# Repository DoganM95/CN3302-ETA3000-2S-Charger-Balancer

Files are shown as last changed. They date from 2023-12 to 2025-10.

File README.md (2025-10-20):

# Intro

A dual cell charger (3-6V 4A in, 8.4V ~3A out) combined with active balancing (1.3A).   
- The charging part makes sure to load the battery pack to 8.4v
- The balancing part makes sure to keep both batteries at the same voltage always, by charging the lower one using the higher one (active balancing)

Having these combined will in theory give the perfect 2S bms, so that batteries won't die, charge fast and don't waste energy.  

Any buyable bms i have tested so far fails to keep both batteries at the same voltage, so that one is e.g. 4.6v and the other 3.8v, resulting in 8.4v total but leading to damage/death of the overcharged cell, hence this proect to solve the issue and have a reliable, hackable solution.  

Still in concept phase, highly experimental and untested. Even the pcb traces are not wide enough to support the supplied current and would probably delaminate or catch fire.  

Releases starting with v1 or higher can be used and are tested.

# PCB

<table>
  <tr>
    <td>
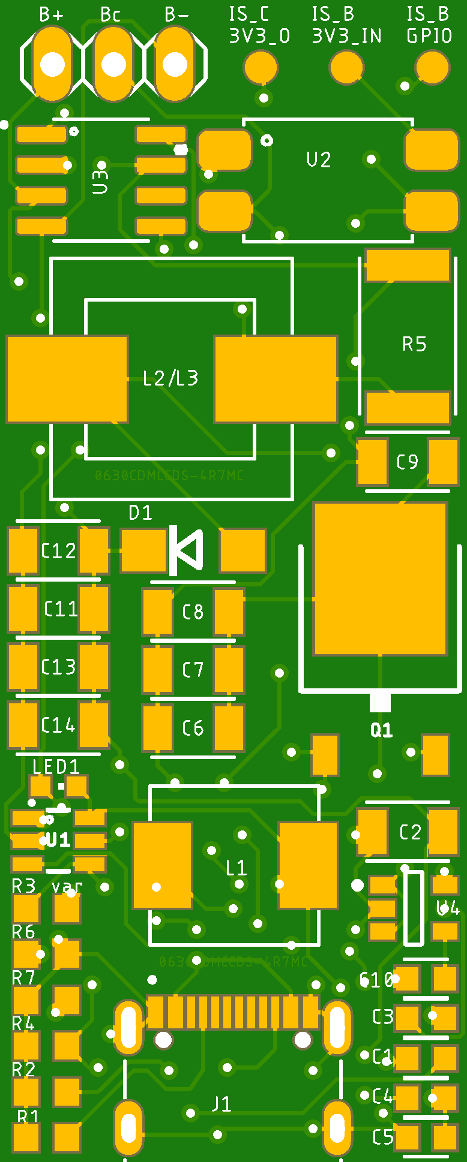
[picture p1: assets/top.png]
PCB Top View
      
    </td>
    <td>
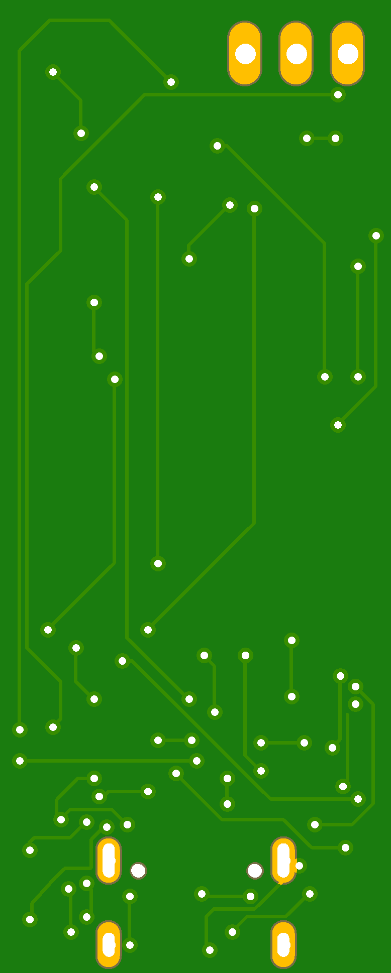
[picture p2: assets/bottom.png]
PCB Bottom View
      
    </td>
  </tr>
</table>

## BOM

Most parts a salvaged from commercially available modules, which are dirt-cheap on aliexpress:
- [Charging module (2S, 4A](https://a.aliexpress.com/_EuYAQFK)
- [Balancing module (2S, 1.3A, active)](https://s.click.aliexpress.com/e/_EuIdQJ6)

So all parts of those modules can be desoldered using a hot-plate and solder3d on this project's pcb.

<table>
  <thead>
    <tr>
      <th>Component Symbol</th>
      <th>Size</th>
      <th>Value</th>
      <th>Side Notes</th>
    </tr>
  </thead>
  <tbody>
    <tr><td>C1</td><td>0603</td><td>10nF</td><td></td></tr>
    <tr><td>C2</td><td>1206</td><td>22uF</td><td></td></tr>
    <tr><td>C3</td><td>0603</td><td>10nF</td><td></td></tr>
    <tr><td>C4</td><td>0603</td><td>10nF</td><td></td></tr>
    <tr><td>C5</td><td>0603</td><td>10nF</td><td></td></tr>
    <tr><td>C6</td><td>1206</td><td>22uF</td><td></td></tr>
    <tr><td>C7</td><td>1206</td><td>22uF</td><td></td></tr>
    <tr><td>C8</td><td>1206</td><td>22uF</td><td></td></tr>
    <tr><td>C9</td><td>1206</td><td>22uF</td><td></td></tr>
    <tr><td>C10</td><td>0603</td><td>10nF</td><td></td></tr>
    <tr><td>C11</td><td>1206</td><td>22uF</td><td></td></tr>
    <tr><td>C12</td><td>1206</td><td>22uF</td><td></td></tr>
    <tr><td>C13</td><td>1206</td><td>22uF</td><td></td></tr>
    <tr><td>C14</td><td>1206</td><td>22uF</td><td></td></tr>
    <tr><td>D1</td><td>sma</td><td>SS54 (Schottky)</td><td></td></tr>
    <tr><td>L1</td><td>0630 (6.6x6.6x3mm)</td><td>2.2 uH</td><td></td></tr>
    <tr><td>L2 / L3</td><td>any</td><td>2.2 uH</td><td>any that fits there by size</td></tr>
    <tr><td>LED1</td><td>0603</td><td>led</td><td>any color, check R3</td></tr>
    <tr><td>Q1</td><td>TO-252-2</td><td>KND3203b</td><td></td></tr>
    <tr><td>R1</td><td>0603</td><td>5.1 kOhm</td><td></td></tr>
    <tr><td>R2</td><td>0603</td><td>5.1 kOhm</td><td></td></tr>
    <tr><td>R3</td><td>0603</td><td>var Ohm</td><td>choose one that fits your LED1</td></tr>
    <tr><td>R4</td><td>0603</td><td>25 kOhm</td><td></td></tr>
    <tr><td>R5</td><td>2512</td><td>0.015 Ohm</td><td></td></tr>
    <tr><td>R6</td><td>0603</td><td>10 kOhm</td><td></td></tr>
    <tr><td>R7</td><td>0603</td><td>10 kOhm</td><td></td></tr>
    <tr><td>U1</td><td>sot23-6</td><td>ETA3000</td><td></td></tr>
    <tr><td>U2</td><td>smt</td><td>PC817X</td><td></td></tr>
    <tr><td>U3</td><td>sop8</td><td>CN3302</td><td></td></tr>
    <tr><td>U4</td><td>sot23-5</td><td>MIC5219 3.3v</td><td></td></tr>
  </tbody>
</table>

## Schematic

### By Datasheets

Follows the recommendations and schematics of the datasheets



### By reverse engineered chinese modules

Follows the reverse engineered chinese pcb modules, so they are merged into this pcb to minimize the need of additional components (just move parts over).

Todo

## Key Takeaways

- The status group of the `ETA3000` consisting of a red led and a 1k resistor use `BatC` as one pole and `SW` as the other. Thus it does not have a real `GND` but current flows with `BatC` acting as Vcc and `SW` acting as `GND` for the led
- The said red status led connections could also be exploited to power an optocoupler, so the `GND` stays independent for this part of the circuit and status becomes measurable using e.g. an arduino
- Connecting `BIAS` or `SW` of the `ETA3000` to the `GND`, which is the negative side of the 2 batteries connected in series, kills the IC and from there it gets very hot while being powered
- None of the 2 ic's (CN3302 && ETA3000) have a symbol in snapeda, so generic packages are used and pins renamed to match this ic

## Resources

### Charger IC: CN3302 (sop-8)

- [Datasheet (EN) of CN3302](https://github.com/DoganM95/2S-Charge-Balance-Pcb/files/13642784/CN3302.zh-CN.en.pdf)
- [Datasheet (CN) of CN3302](https://jlcpcb.com/partdetail/ShangHai_ConsonanceElec-CN3302/C559039)

### Active balancer IC: ETA3000 (sot23-6)
- [Writeup on ETA3000](https://www.beyondlogic.org/review-li-ion-lipo-lifepo4-lithium-battery-active-equalizer-balancer-energy-transfer-board/)
- [Datasheet of ETA3000](https://github.com/DoganM95/2S-Charge-Balance-Pcb/files/13648156/ETA3000-ETA.pdf)

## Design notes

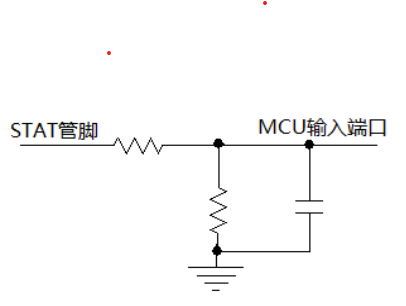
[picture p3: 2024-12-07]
assets/snippet.png

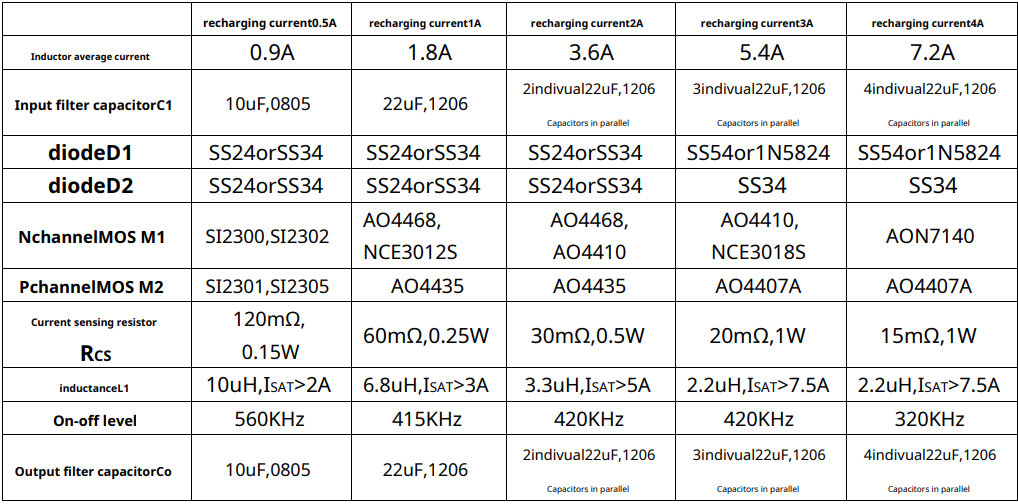
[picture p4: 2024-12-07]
assets/table.png

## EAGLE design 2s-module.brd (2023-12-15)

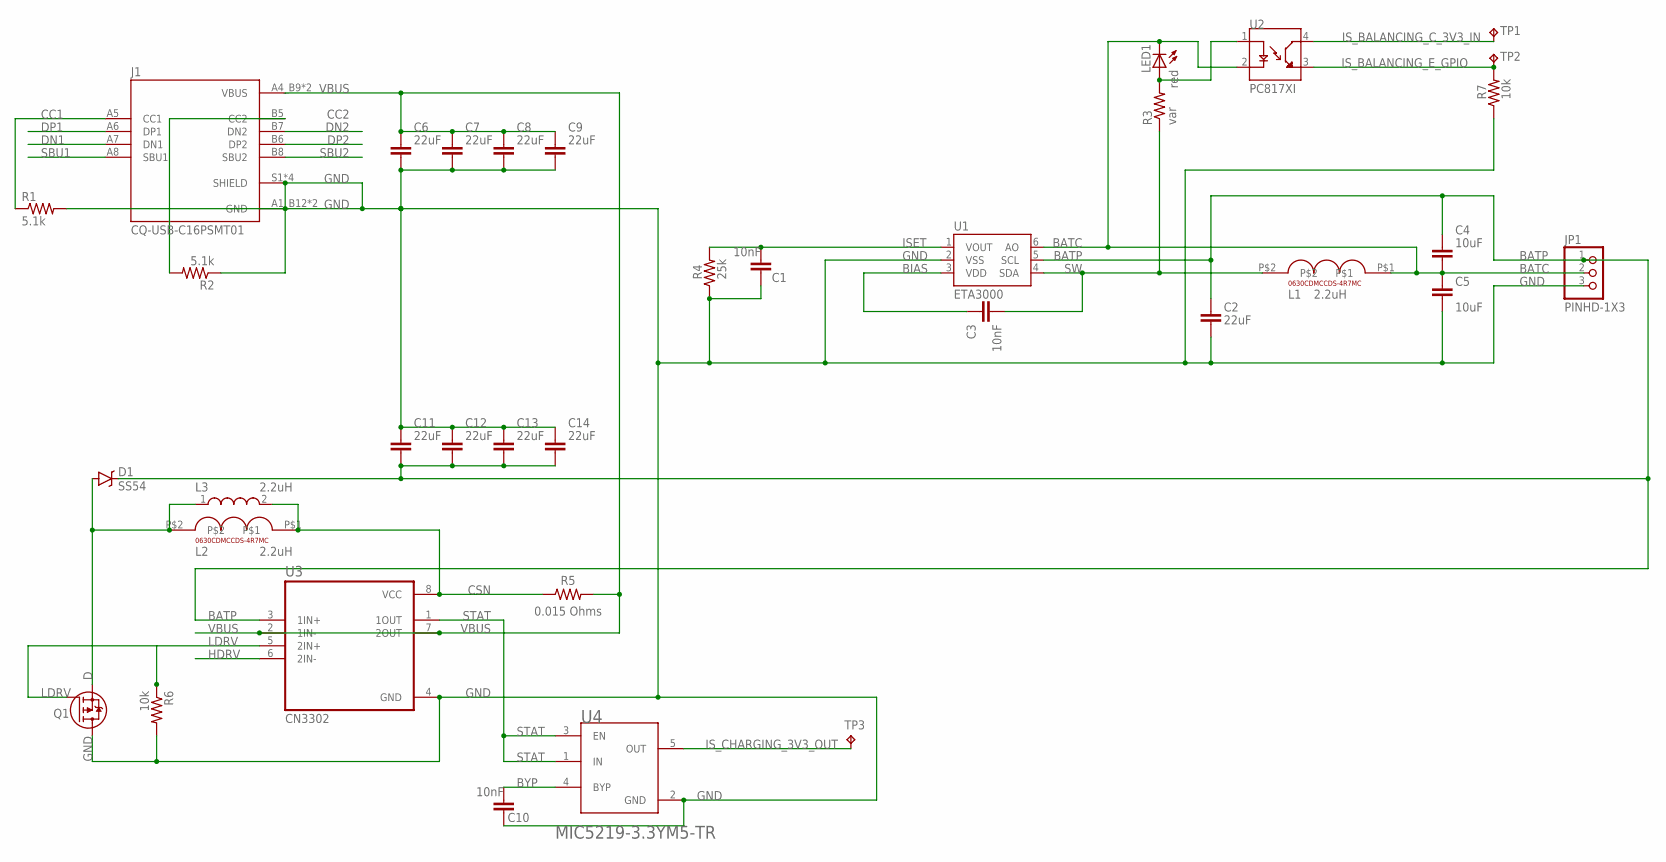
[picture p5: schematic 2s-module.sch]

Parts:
C1, C3, C10: 10nF; CAPC1608X85
C2, C6, C7, C8, C9, C11, C12, C13, C14: 22uF; CAPC3216X135
C4, C5: 10uF; CAPC1608X85
D1: SS54; DO-214AC
J1: CQ-USB-C16PSMT01; SHENZHEN-CHUANGQIN-TECHNOLOGY_CQ-USB-C16PSMT01
JP1: PINHD-1X3; 1X03
L1: 0630CDMCCDS-4R7MC
L2: 2.2uH; 0630CDMCCDS-4R7MC
L3: 2.2uH; INDM110100X380N
LED1: red; CHIPLED_0603
Q1: IRFR9020A; TO252
R1, R2: 5.1k; R0603
R3: var; R0603
R4: 25k; R0603
R5: 0.015 Ohms; RESC6332X71
R6, R7: 10k; R0603
TP1, TP2, TP3: TPB1,27; B1,27
U1: MCP4725; SOT23-6
U2: PC817XI; SOIC254P975X460-4N
U3: LM393DR; SOIC127P599X175-8N
U4: MICROCHIP_MIC5219-3_3YM5-TRMICROCHIP_MIC5219-3_3Y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; MICROCHIP_MIC5219-3_3YM5-TR_0

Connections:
BATC: C4.2, C5.1, JP1.2, L1.P$1, LED1.C, U1.6 (AO), U2.2 (C)
BATP: C2.1, C4.1, C11.2, C12.2, C13.2, C14.2, D1.C, JP1.1, U1.5 (SCL), U3.3 (1IN+)
BIAS: C3.2, U1.3 (VDD)
BYP: C10.2, U4.4 (BYP)
CC1: J1.A5 (CC1), R1.1
CC2: J1.B5 (CC2), R2.2
CSN: L2.P$1, L3.2, R5.1, U3.8 (VCC)
D: D1.A, L2.P$2, L3.1, Q1.2 (S)
DN1: J1.A7 (DN1)
DN2: J1.B7 (DN2)
DP1: J1.A6 (DP1)
DP2: J1.B6 (DP2)
GND: C1.1, C2.2, C5.2, C6.2, C7.2, C8.2, C9.2, C10.1, C11.1, C12.1, C13.1, C14.1, J1.A1_B12 (GND), J1.B1_A12 (GND), J1.S1 (SHIELD), J1.S2 (SHIELD), J1.S3 (SHIELD), J1.S4 (SHIELD), JP1.3, Q1.3 (D), R1.2, R2.1, R4.1, R6.2, R7.1, U1.2 (VSS), U3.4 (GND), U4.2 (GND)
HDRV: U3.6 (2IN-)
ISET: C1.2, R4.2, U1.1 (VOUT)
IS_BALANCING_C_3V3_IN: TP1.TP, U2.4 (CT)
IS_BALANCING_E_GPIO: R7.2, TP2.TP, U2.3 (ET)
IS_CHARGING_3V3_OUT: TP3.TP, U4.5 (OUT)
LDRV: Q1.1 (G), R6.1, U3.5 (2IN+)
unnamed: LED1.A, R3.2, U2.1 (A)
SBU1: J1.A8 (SBU1)
SBU2: J1.B8 (SBU2)
STAT: U3.1 (1OUT), U4.1 (IN), U4.3 (EN)
SW: C3.1, L1.P$2, R3.1, U1.4 (SDA)
VBUS: C6.1, C7.1, C8.1, C9.1, J1.A4_B9 (VBUS), J1.B4_A9 (VBUS), R5.2, U3.2 (1IN-), U3.7 (2OUT)

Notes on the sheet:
ETA3000
2.2uH
CN3302

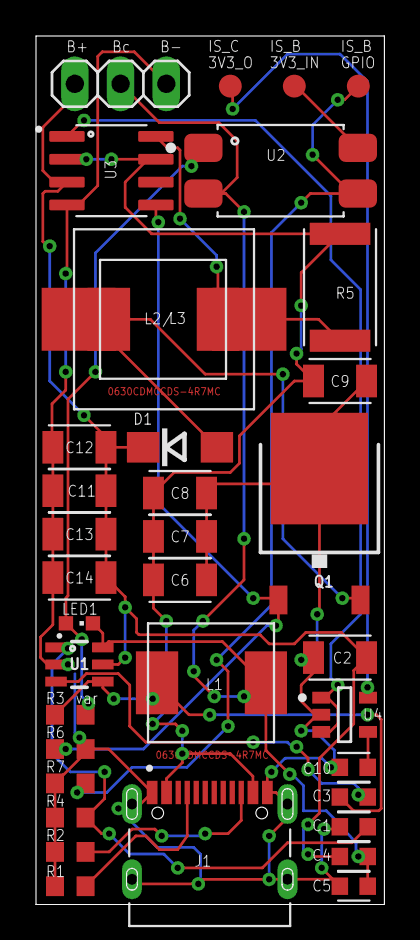
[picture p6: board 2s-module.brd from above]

Board: 2 copper layers, 19.4 x 48.2 mm, 36 parts (0 on the bottom side), 18 nets.

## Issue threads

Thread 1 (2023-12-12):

Resources

DoganM95, 2023-12-12:
Charger ic: CN3302 (sop-8)

- [CN3302.zh-CN.en.pdf](https://github.com/DoganM95/2S-Charge-Balance-Pcb/files/13642784/CN3302.zh-CN.en.pdf)
- https://jlcpcb.com/partdetail/ShangHai_ConsonanceElec-CN3302/C559039

Active balancer ic: ETA3000 (sot23-6)
- https://www.beyondlogic.org/review-li-ion-lipo-lifepo4-lithium-battery-active-equalizer-balancer-energy-transfer-board/
- [ETA3000-ETA.pdf](https://github.com/DoganM95/2S-Charge-Balance-Pcb/files/13648156/ETA3000-ETA.pdf)

None of the 2 ic's have a symbol in snapeda, so generic packages could be used and pins renamed to match this ic.

DoganM95, 2024-01-12:
integrated into readme

Closed 2024-01-12.

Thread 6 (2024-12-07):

Make Frankenstein

DoganM95, 2024-12-07:
Check if current model is compatible with ddtccrub's components, so the pcb of them can be ordered and salvaged to populate the charger part of this pcb.
Same goes for the balancing part.

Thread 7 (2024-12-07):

Thicken traces

DoganM95, 2024-12-07:
pcb is capable of charging batteries with 4A, whcih will require thicc traces.

make traces wider and consider exposing the traces to create a solder path for high current throughput.

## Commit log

2023-12-12 init schematic & board
    [2s-module.brd, 2s-module.sch]
2023-12-12 build balancer prototype
    [2s-module.brd, 2s-module.sch]
2023-12-12 add optocoupler
    [2s-module.brd, 2s-module.sch]
2023-12-13 finish initial prototype, inductors may change
    [2s-module.brd, 2s-module.sch]
2023-12-14 fix some parts in sch
    [2s-module.brd, 2s-module.sch]
2023-12-15 add fallback inductor
    [2s-module.sch]
2023-12-15 build board to be wired
    [2s-module.brd]
2023-12-15 add alternative direction indicators
    [2s-module.brd]
2023-12-15 rearrange more to save space
    [2s-module.brd]
2023-12-15 move buried component
    [2s-module.brd]
2023-12-15 route airwires
    [2s-module.brd]
2023-12-15 low amp version, to be overwritten with new design
    [2s-module.brd]
2024-12-07 update BOM for assembly
2024-12-07 fix bom order
2024-12-09 turn bom into table

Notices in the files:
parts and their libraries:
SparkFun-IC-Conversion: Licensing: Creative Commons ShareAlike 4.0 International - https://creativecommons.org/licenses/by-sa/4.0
